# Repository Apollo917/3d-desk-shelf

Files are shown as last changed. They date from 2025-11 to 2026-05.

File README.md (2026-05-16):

<div align="center">

# TDS | Tubed Desk Shelf

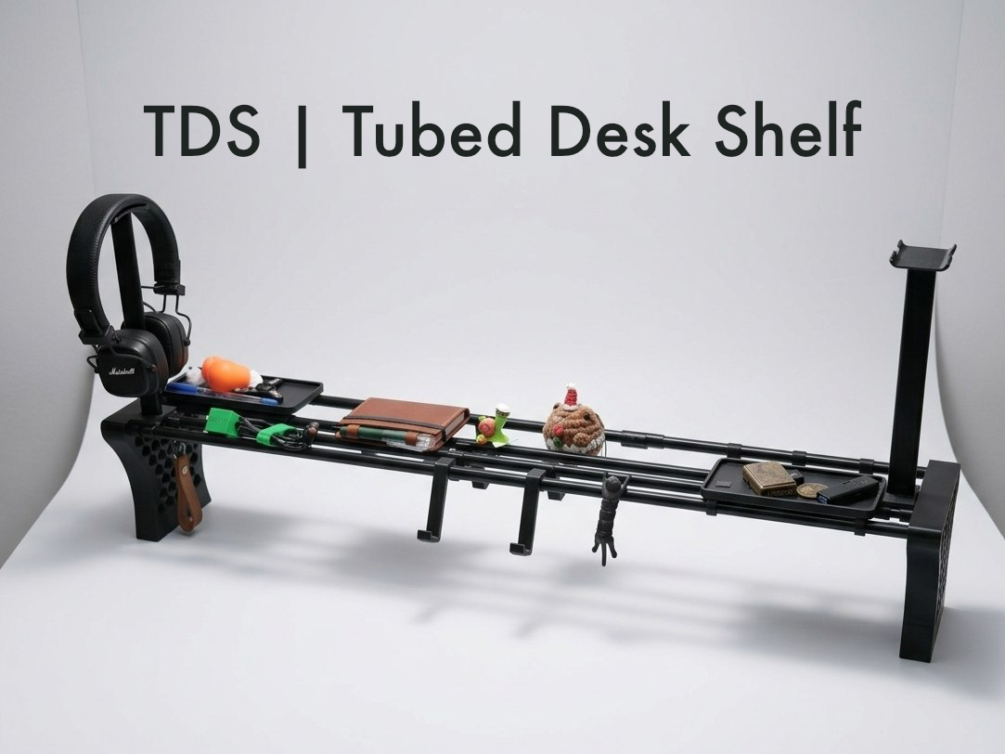
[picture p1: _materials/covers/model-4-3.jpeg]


</div>
<br>

**TDS** is an open-source, 3D-printable modular system designed to organize and elevate your workspace.
The structure is built around side supports and five 13mm-diameter tubes/rods of any material - such as aluminum, wood,
or carbon fiber. These core elements form the basic TDS, which you can secure it to your workspace using the dedicated
table mounts and expand its functionality with the initial set of compatible accessories, or design your own custom
additions. I also welcome your ideas and proposals for future expansions

**TDS** project was designed in **Autodesk Fusion** and the repository includes both the **Fusion project files** and
**.3mf files** preconfigured for the **Bambu Lab P1S** 3D printer

## Links

- [Maker World](https://makerworld.com/en/models/2803112-tds-tubed-desk-shelf#profileId-3118631)

## Ecosystem

- **Main parts**
    - [Tubed Desk Shelf](tubed-desk-shelf)
- **Accessories**
    - [Intermediate Supports](intermediate-supports)
    - [Headphones stand](headphones-stand)
    - [Tray](tray)
    - [Phone stand](phone-stand)
    - [Notebooks holder](notebook-holder)
    - [Cables holder](cables-holder)
    - [Headphones stand base](headphones-stand-base)
    - [dev kit](dev-kit)

## Specs

### Dimensions

- **Height:** 150mm
- **Width:** depends on the tube length you choose
- ⚠️ **NOTE** ⚠️
    - When marking the holes, keep in mind that each screw hole should be positioned **~39mm behind the front edge of
      the side stand** - this ensures that the shelf will sit exactly where you want it on your desk
    - Keep in mind that some accessories, or certain ways of using them, may require additional vertical space -
      consider this when positioning the shelf

### Required materials

- ~292g of PLA filament for the base shelf
- ~445g of PLA filament for the base shelf and accessories
- 5 tubes/rods with a 13mm outer diameter
- 2 x M4 x 30mm screws
    - The screws length depends on your desk thickness

## Preview

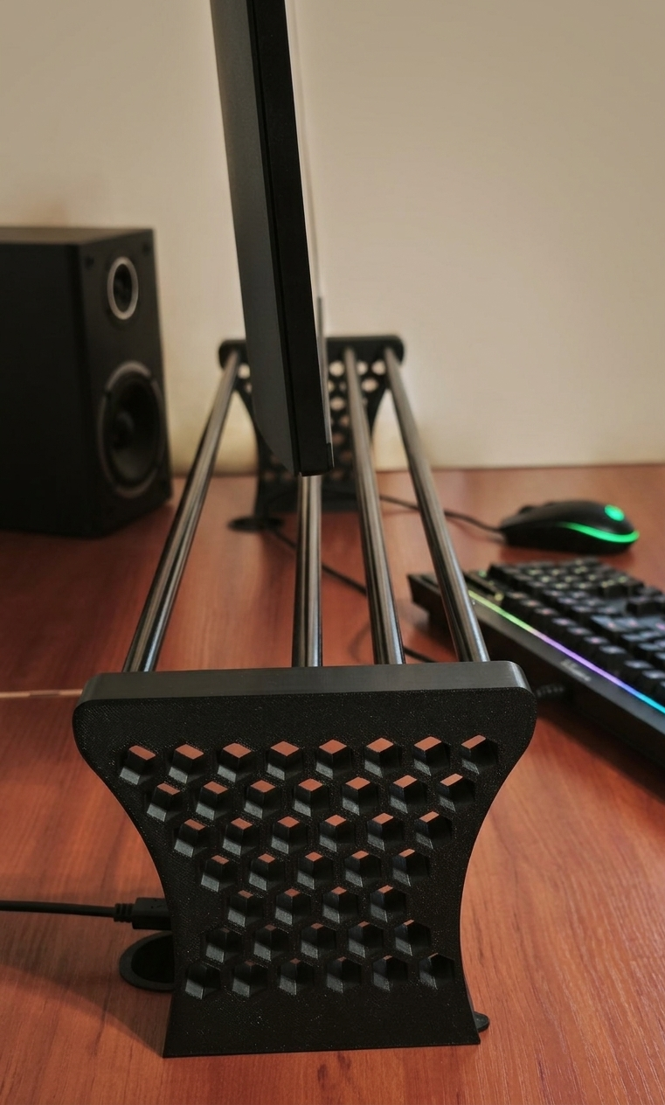
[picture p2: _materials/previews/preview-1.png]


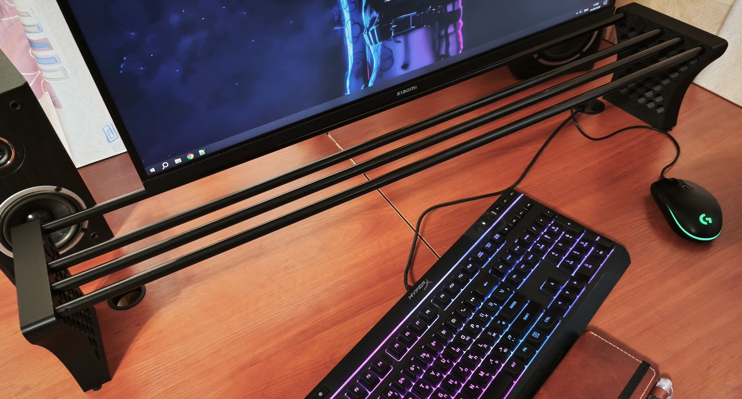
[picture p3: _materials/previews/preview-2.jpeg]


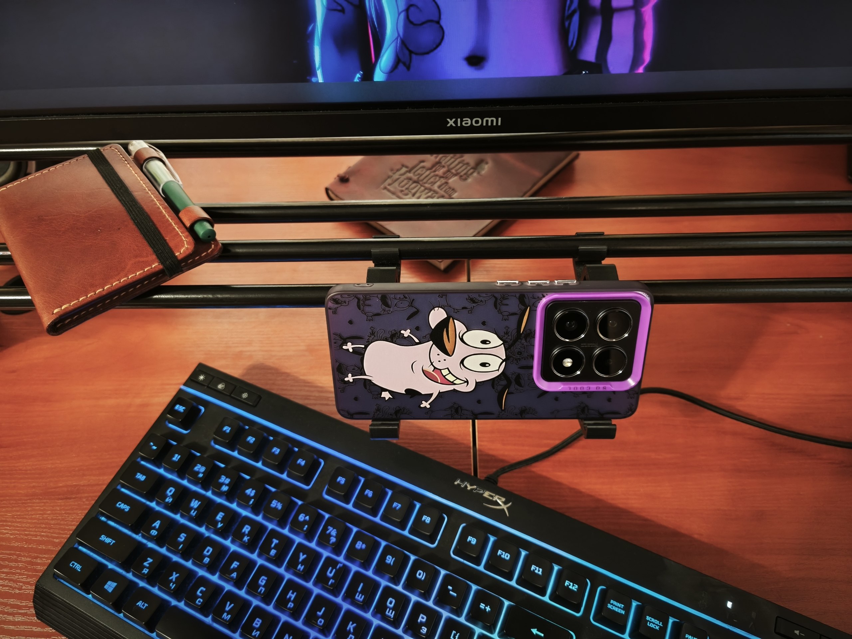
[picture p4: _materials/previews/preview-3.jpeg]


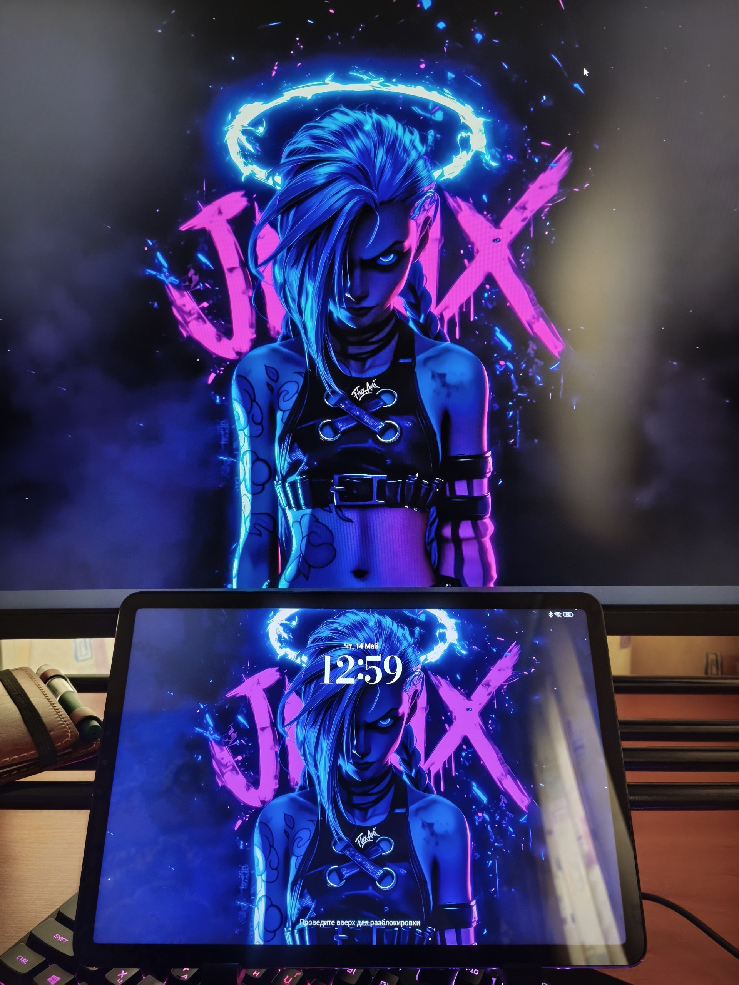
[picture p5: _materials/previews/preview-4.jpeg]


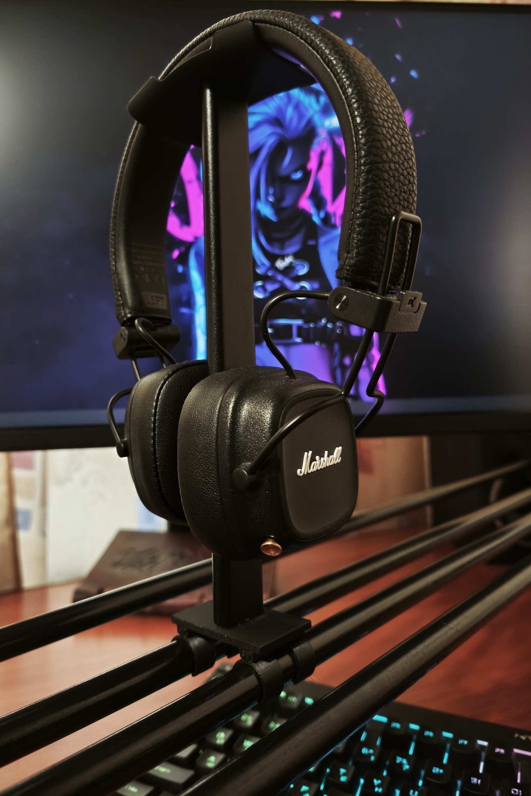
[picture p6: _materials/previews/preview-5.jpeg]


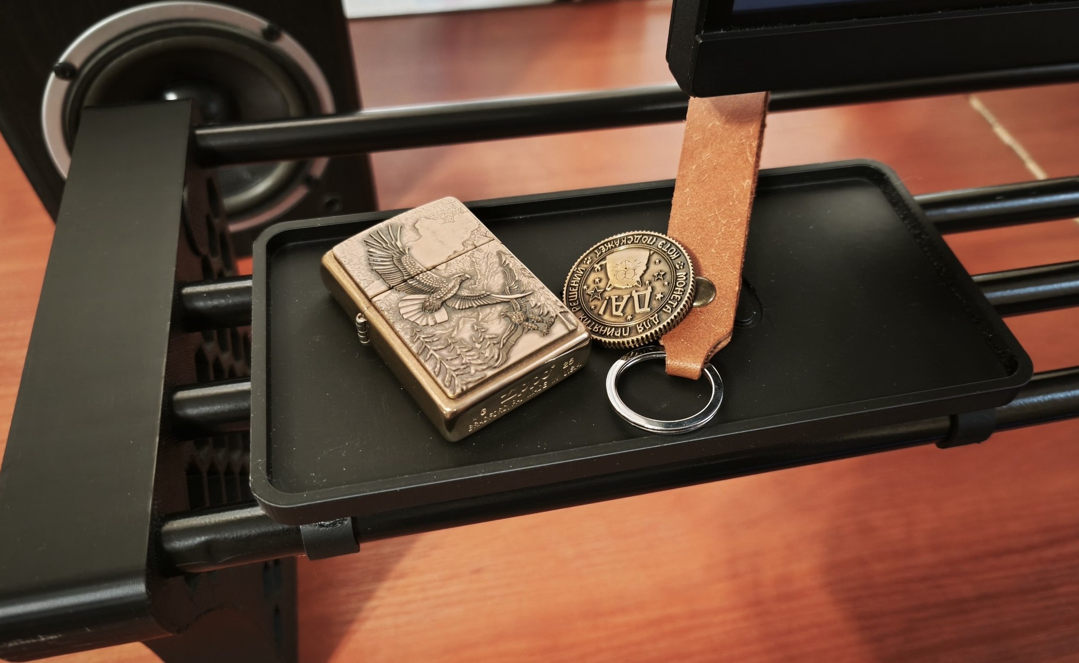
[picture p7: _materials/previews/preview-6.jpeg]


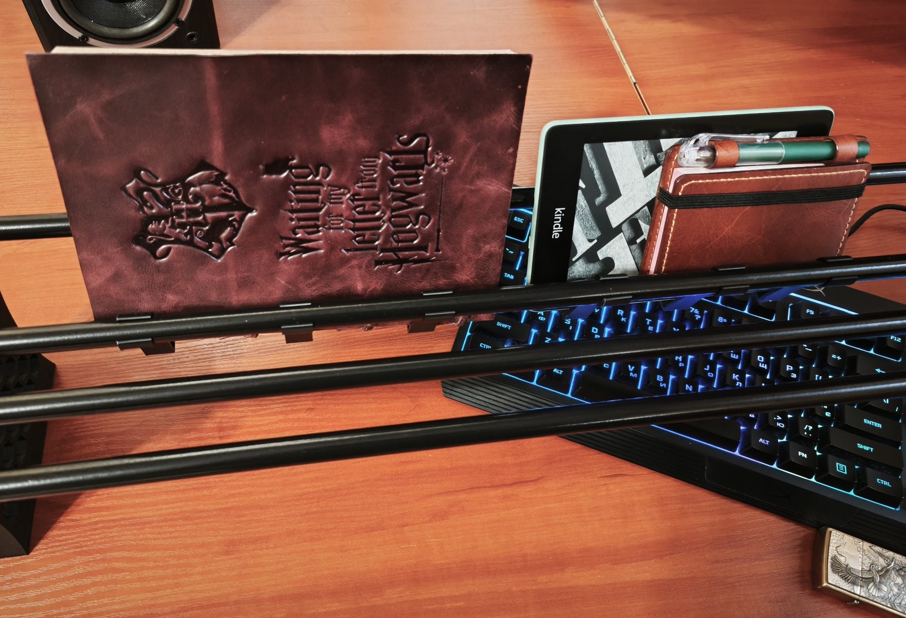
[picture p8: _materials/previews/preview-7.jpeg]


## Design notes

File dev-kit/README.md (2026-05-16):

### Dev kit

A set of essential components designed to bootstrap the development process for your own TDS accessories

## Files

- [Bambu Studio .3mf file](templates.3mf)
- [Fusion .f3d file](templates.f3d)
- [.step file](templates.step)

## Preview

### 3D

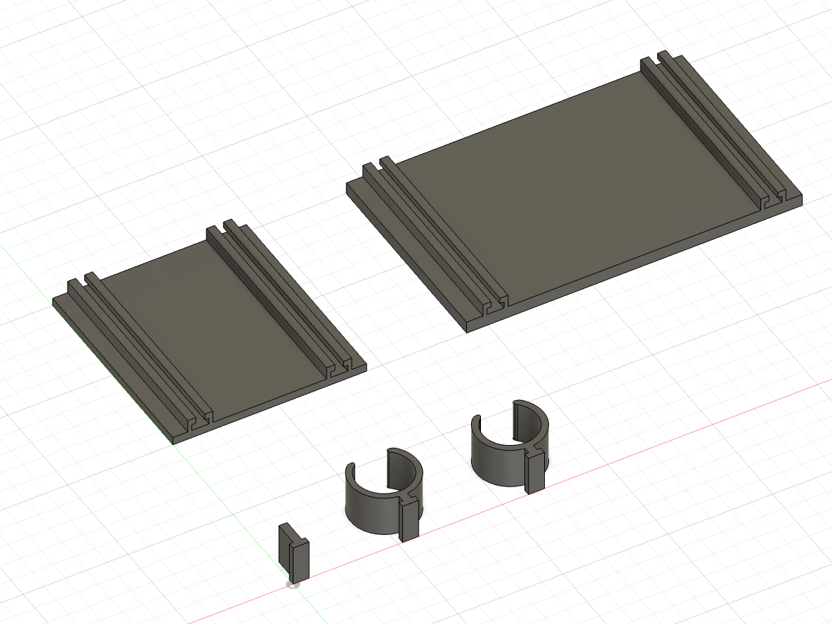
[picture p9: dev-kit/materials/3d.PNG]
Tube brackets


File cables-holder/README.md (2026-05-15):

# Cables holder

TDS-compatible accessory that keeps your keyboard, mouse, or other cables organized. You can also use it to hang small
accessories or tools

## Specs

### Required materials

**Filament required:** ~3g

## Files

- [Bambu Studio .3mf file](cables-holder.3mf)
- [Fusion .f3d file](cables-holder.f3d)
- [.step file](cables-holder.step)

## Preview

### 3D

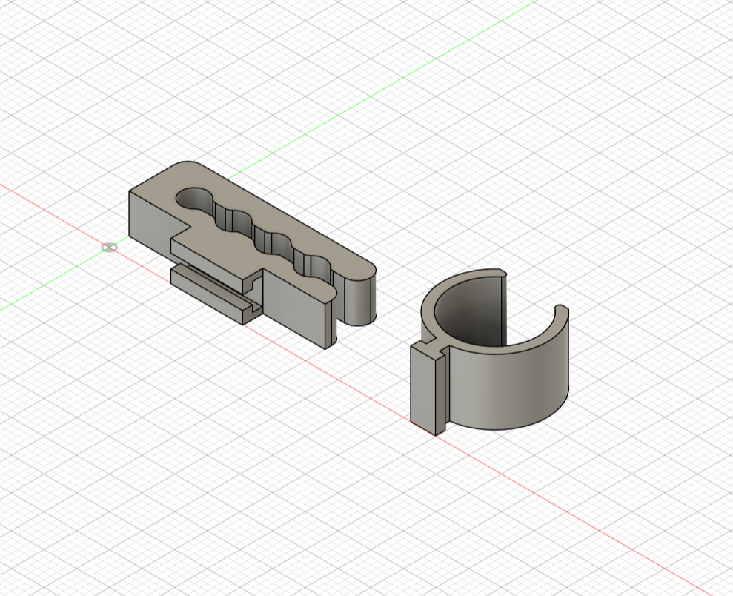
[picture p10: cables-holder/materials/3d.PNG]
Cables holder


### Printed

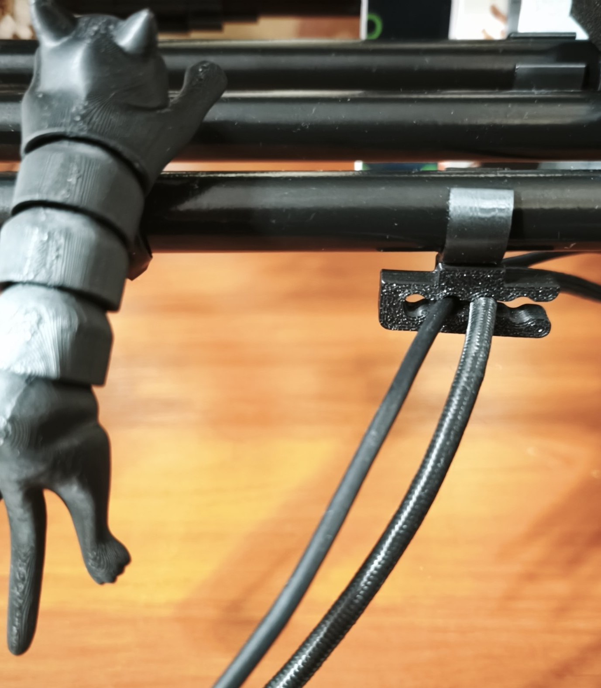
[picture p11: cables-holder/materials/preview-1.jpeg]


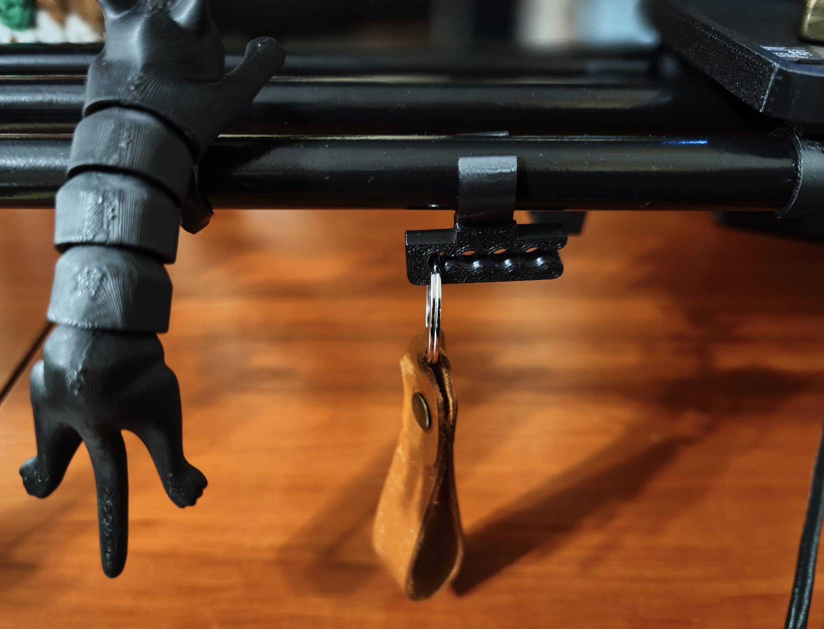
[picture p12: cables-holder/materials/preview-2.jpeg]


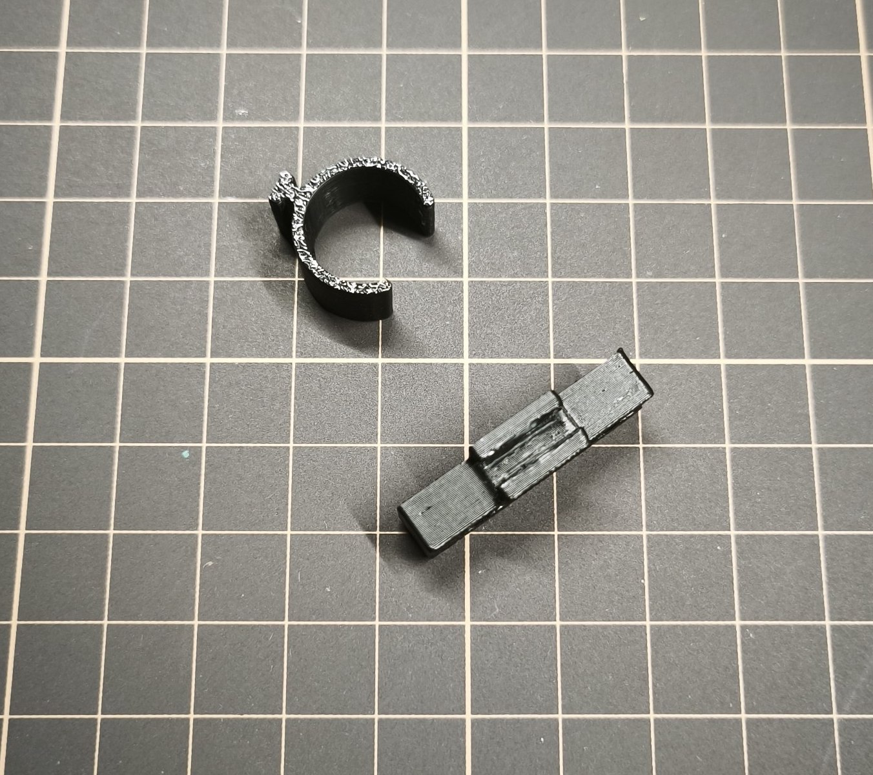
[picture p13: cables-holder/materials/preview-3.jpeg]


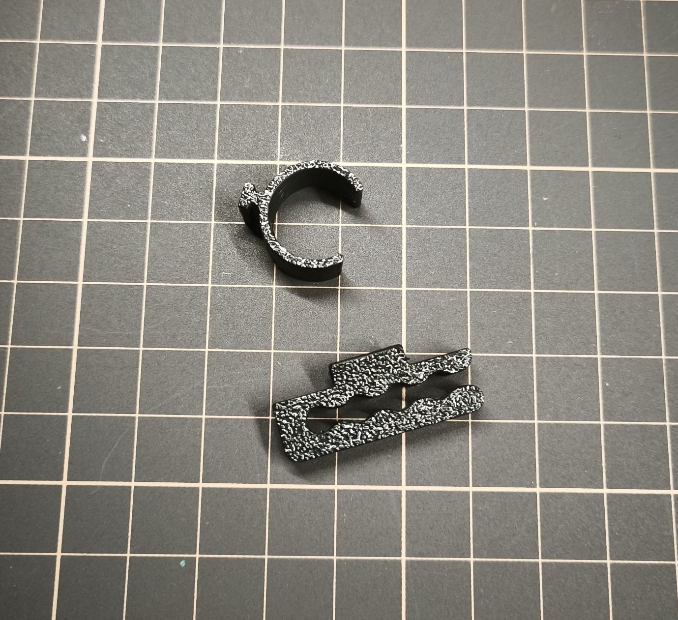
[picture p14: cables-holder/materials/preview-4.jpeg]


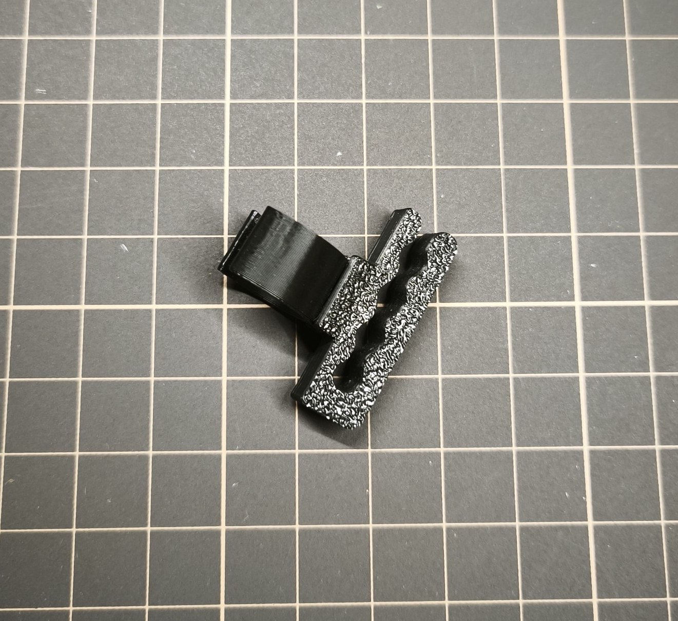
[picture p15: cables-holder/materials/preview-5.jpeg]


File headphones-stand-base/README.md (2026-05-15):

# Headphones stand base

A TDS-compatible replacement for the original baseplate, providing a stable, space-saving mounting solution for your
headphones

## Specs

### Required materials

**Filament required:** ~9g

## Files

- [Bambu Studio .3mf file](headphones-stand-base.3mf)
- [Fusion .f3d file](headphones-stand-base.f3d)
- [.step file](headphones-stand-base.step)

## Preview

### 3D

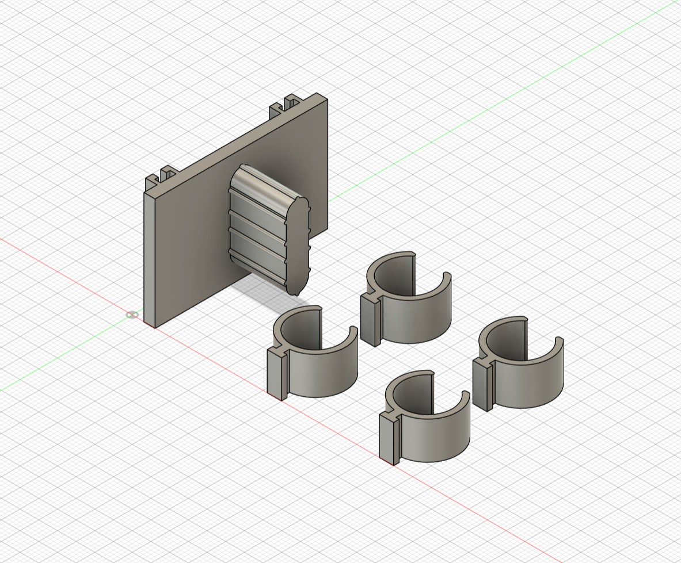
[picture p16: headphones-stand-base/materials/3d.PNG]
Headphones stand base


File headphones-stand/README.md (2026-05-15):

# Headphones stand

TDS-compatible headphones stand, designed to integrate with the shelf’s tube system, providing a stable and space-saving
mounting solution for your headphones

## Specs

### Required materials

**Filament required:** ~46g

## Files

- [Bambu Studio .3mf file](headphones-stand.3mf)
- [Fusion .f3d file](headphones-stand.f3d)
- [.step file](headphones-stand.step)

## Preview

### 3D

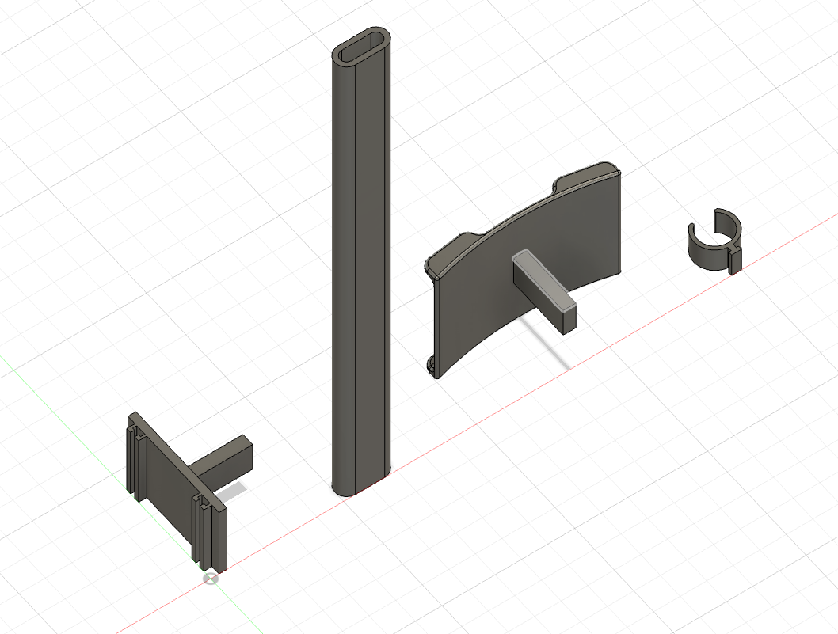
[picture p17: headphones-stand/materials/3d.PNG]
Headphones stand base


### Printed

Shelf mounts

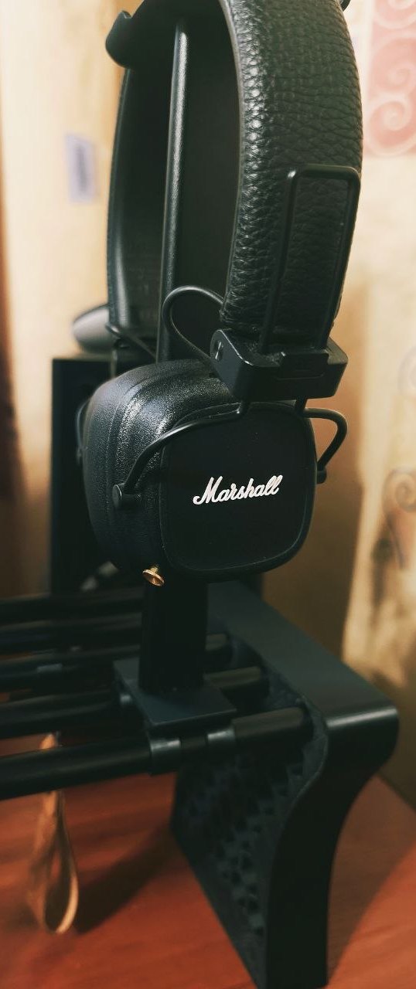
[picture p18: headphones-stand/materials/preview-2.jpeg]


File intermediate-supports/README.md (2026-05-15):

# Intermediate Supports

This extension provides optional structural reinforcement for high-payload scenarios. It is designed to interface
seamlessly with the existing architecture when center-loading (e.g. monitor, etc.) is required

Supports utilize a 13.6mm bore, engineered for a high-clearance "slide-on" fit to ensure effortless positioning
along the support tubes. For users seeking a secure but non-permanent installation, the base is compatible with
double-sided adhesive tape to prevent shifting during use, as the component's main function is to manage vertical
pressure

**Supports come in two designs**

- **Mountable:** includes an integrated base for direct desktop fixation
- **Slim:** a minimalist profile optimized for vertical bracing with a reduced footprint

## Specs

### Required materials

- **Mountable support**
    - ~144g of PLA filament
    - 2 x M4 x 30mm screws
        - The screws length depends on your desk thickness
- **Slim support**
    - ~80g of PLA filament

## Files

- [Bambu Studio .3mf file](intermediate-supports.3mf)
- [Fusion .f3d file](intermediate-supports.f3d)
- [.step file](intermediate-supports.step)

## Preview

### 3D

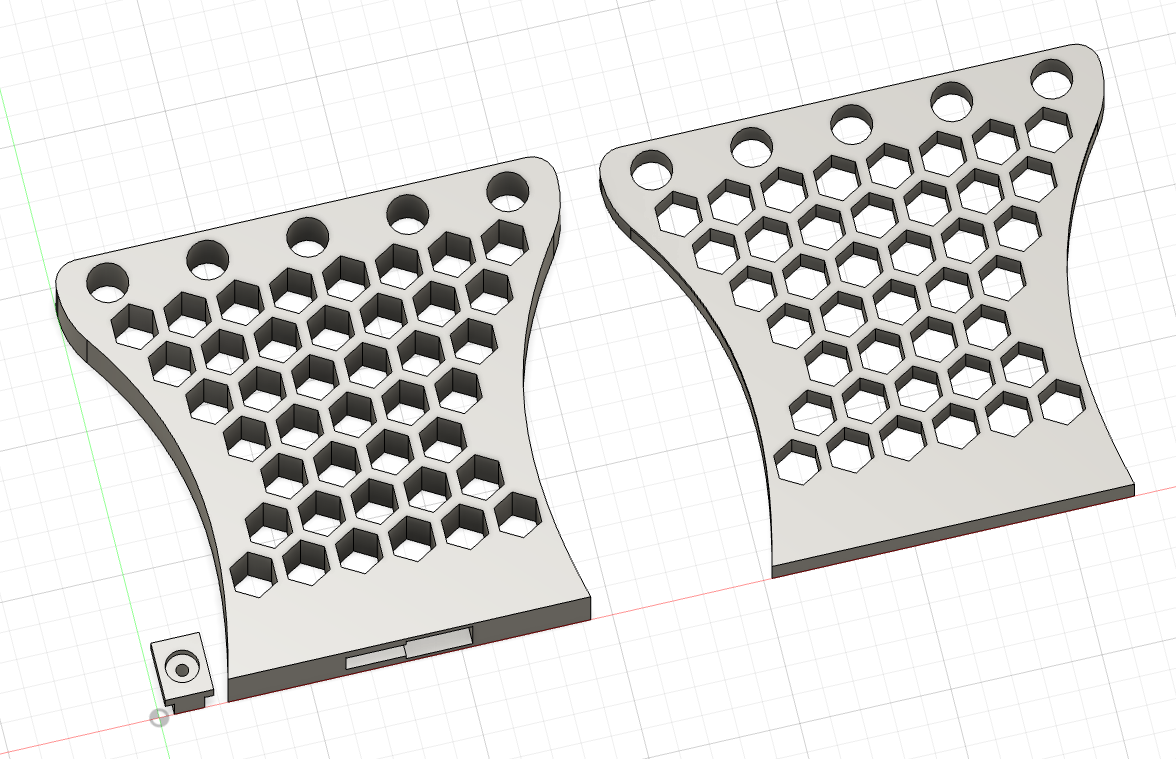
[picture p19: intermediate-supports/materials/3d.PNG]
Shelf mounts


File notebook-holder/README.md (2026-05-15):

### Notebook holder

TDS-compatible flexible holder that attaches to the shelf’s tube system and can hold notebooks, books, or other flat
items. It can be mounted between neighboring or more distant tubes

## Specs

### Required materials

**Filament required:** ~14g for the pair

## Files

- [Bambu Studio .3mf file](notebook-holder.3mf)
- [Fusion .f3d file](notebook-holder.f3d)
- [.step file](notebook-holder.step)

## Preview

### 3D

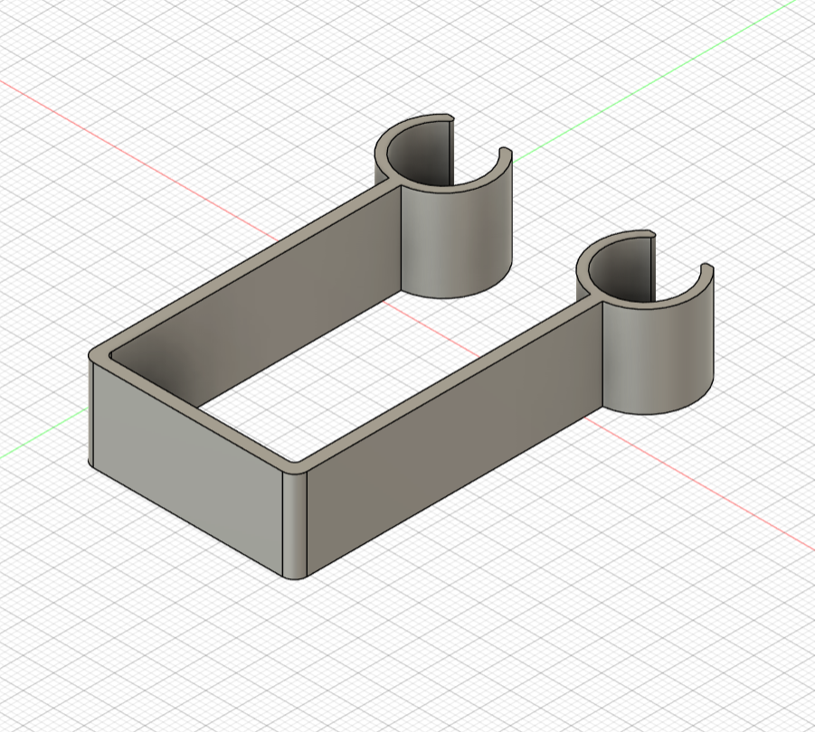
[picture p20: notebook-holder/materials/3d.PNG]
Notebooks holder


### Printed

Shelf mounts

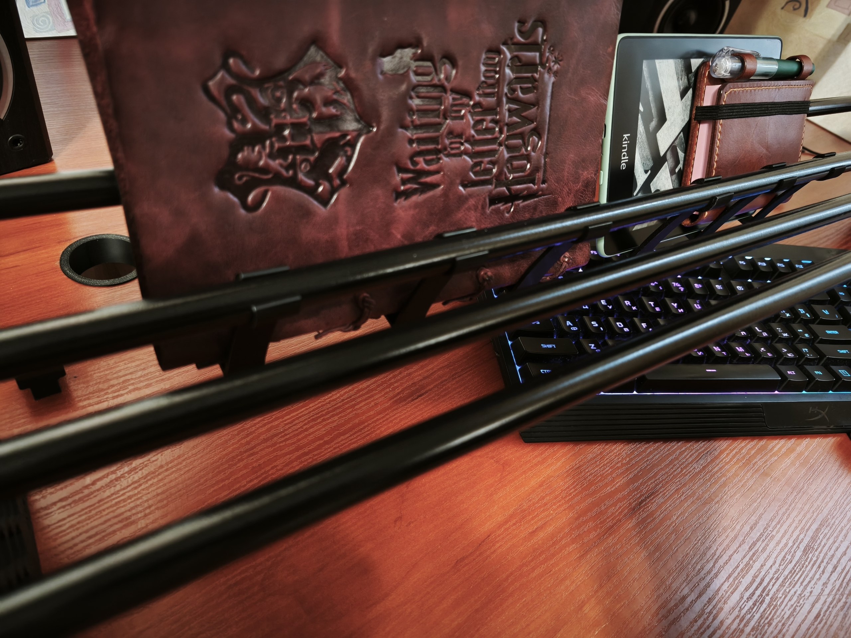
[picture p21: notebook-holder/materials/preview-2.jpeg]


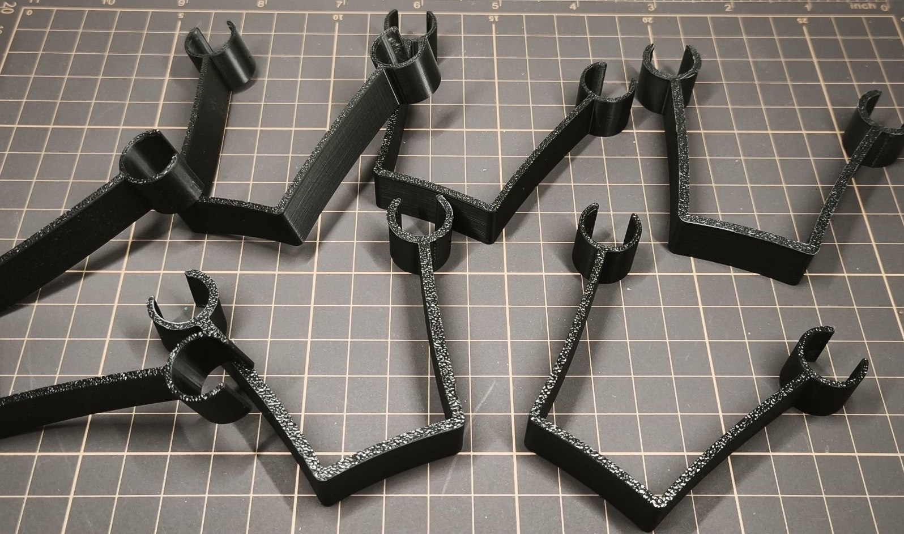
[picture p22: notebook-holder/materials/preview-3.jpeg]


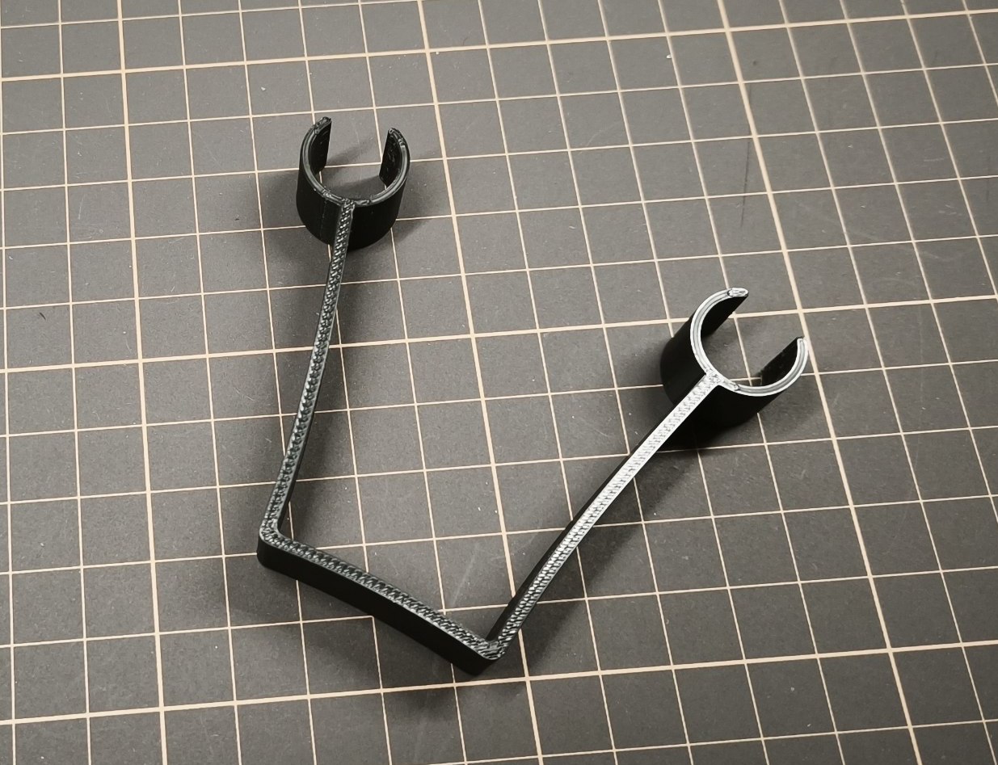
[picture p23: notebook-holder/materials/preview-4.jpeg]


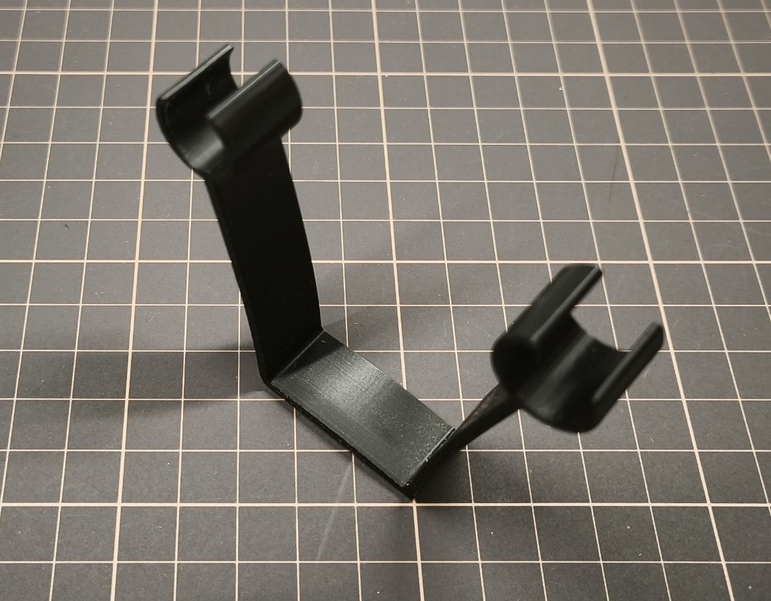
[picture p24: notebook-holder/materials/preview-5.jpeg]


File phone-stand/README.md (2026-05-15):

# Phone stand

TDS-compatible width-adjustable stand suitable for holding various devices such as phones, tablets, e-readers, etc.

## Specs

### Required materials

**Filament required:** ~22g for the pair

## Files

- [Bambu Studio .3mf file](phone-stand.3mf)
- [Fusion .f3d file](phone-stand.f3d)
- [.step file](phone-stand.step)

## Preview

### 3D

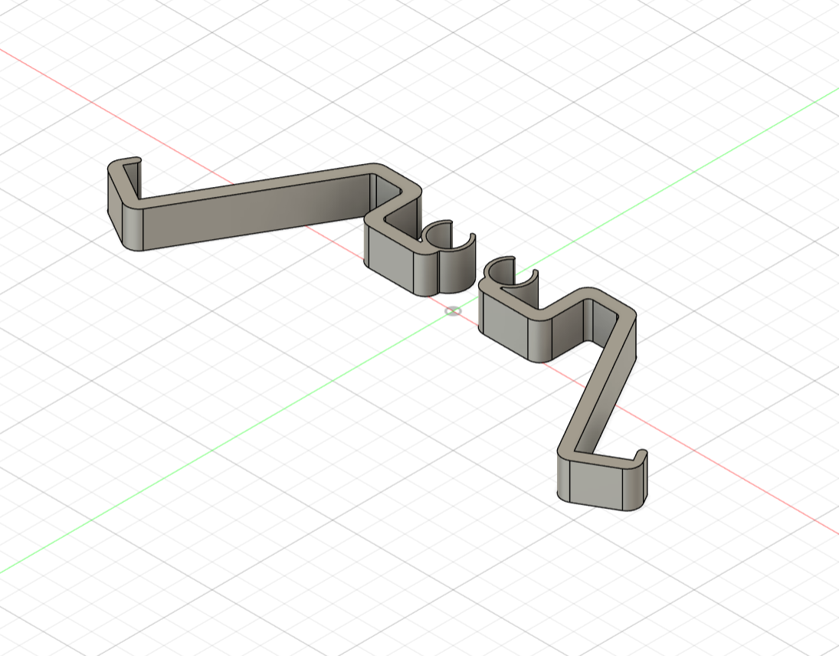
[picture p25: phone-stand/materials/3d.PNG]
Phone stand


### Printed

Shelf mounts

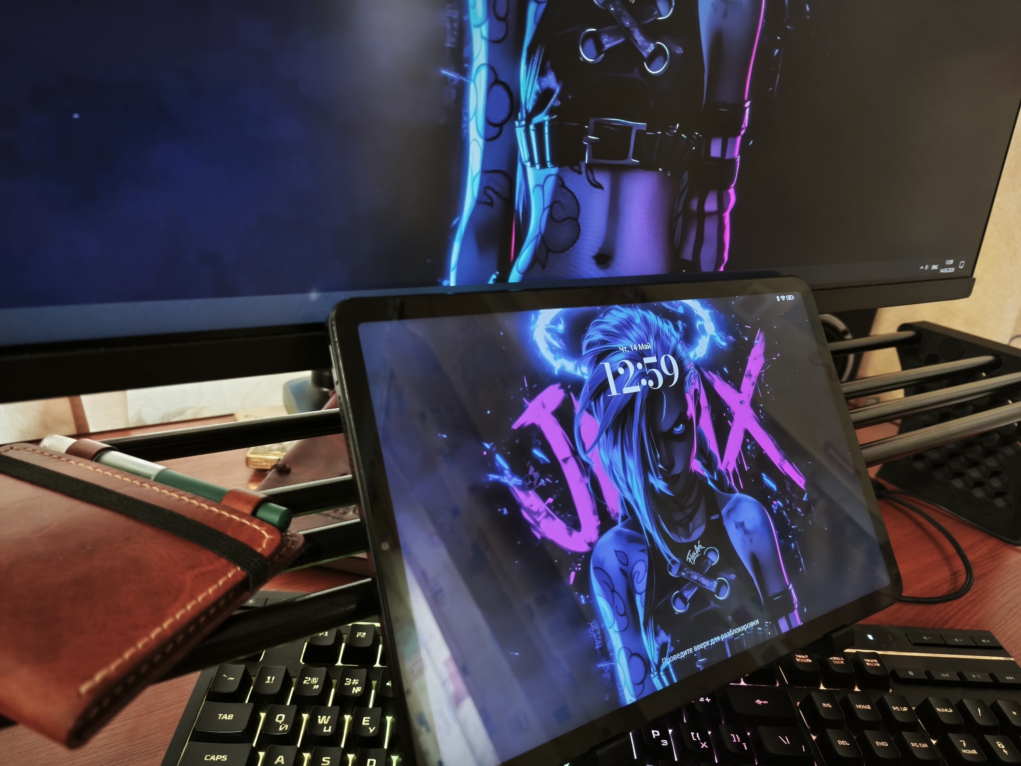
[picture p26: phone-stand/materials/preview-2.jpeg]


Shelf mounts

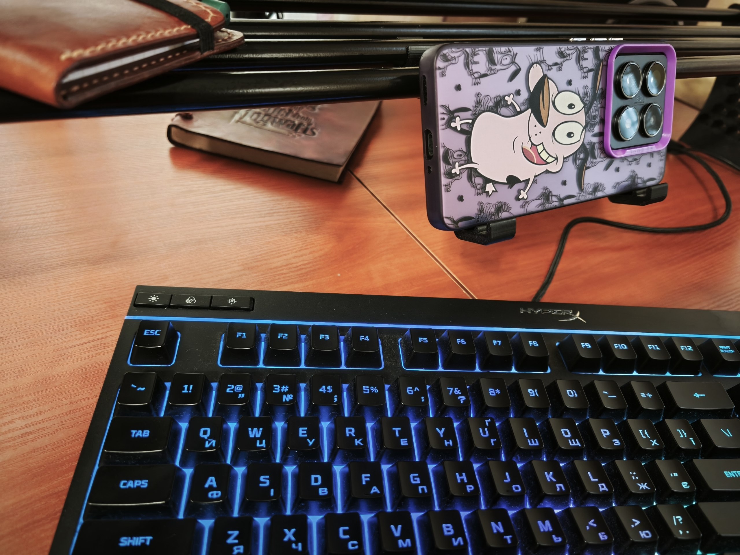
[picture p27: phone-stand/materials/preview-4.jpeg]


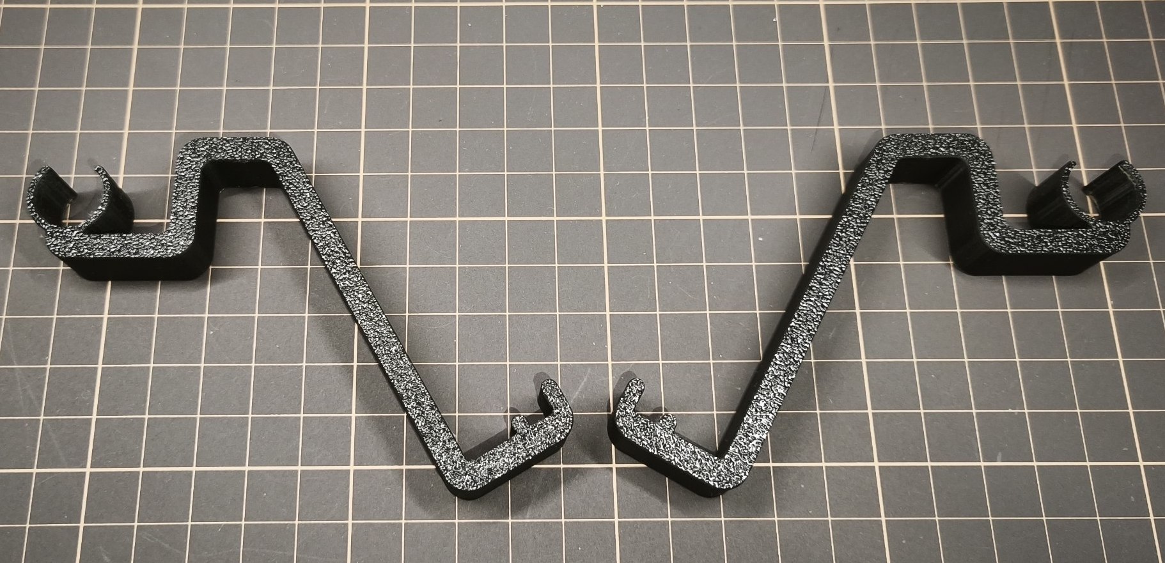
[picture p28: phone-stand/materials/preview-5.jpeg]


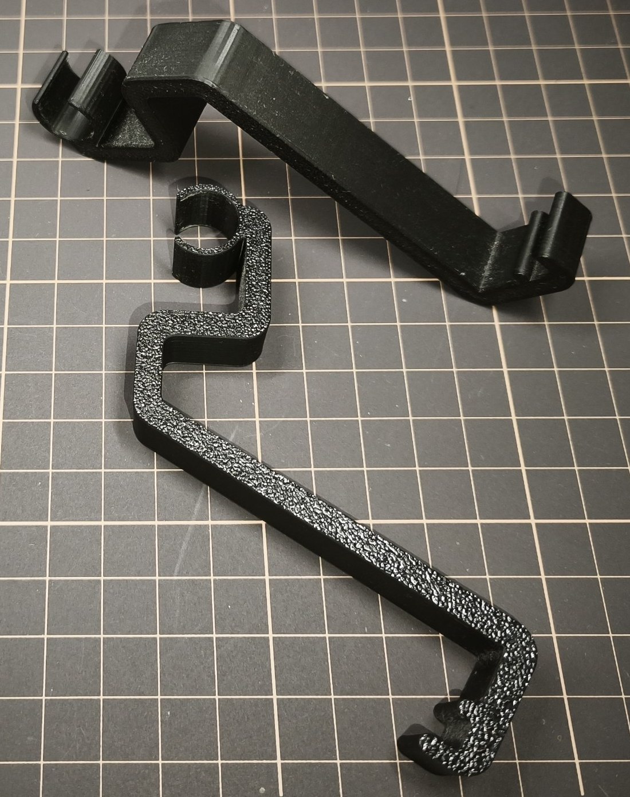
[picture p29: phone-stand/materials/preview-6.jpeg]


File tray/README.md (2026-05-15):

# Tray

TDS-compatible tray accessory, that provides convenient storage for frequently used pens, cables, and small items

## Specs

### Required materials

**Filament required:** ~59g

## Files

- [Bambu Studio .3mf file](tray.3mf)
- [Fusion .f3d file](tray.f3d)
- [.step file](tray.step)

## Preview

### 3D

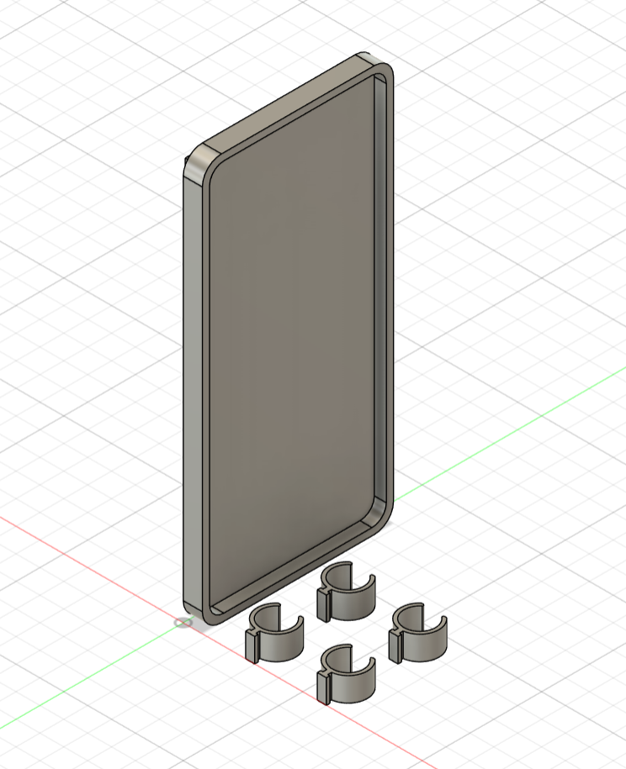
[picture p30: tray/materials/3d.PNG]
Tray


### Printed

Shelf mounts

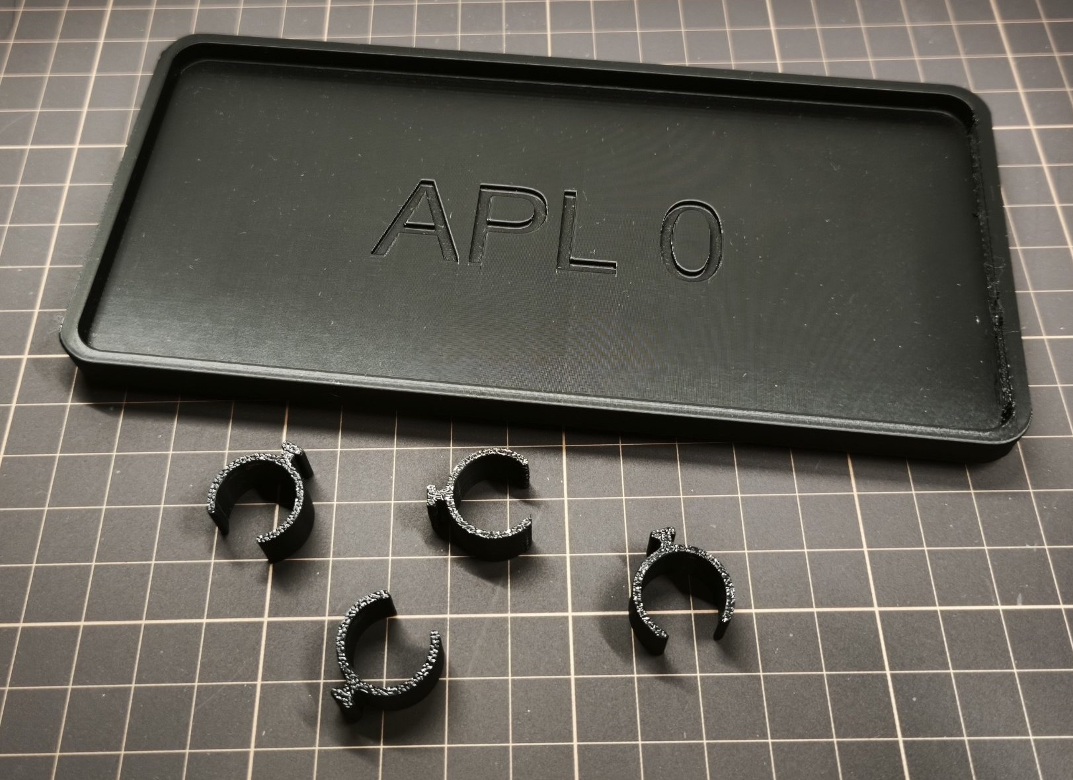
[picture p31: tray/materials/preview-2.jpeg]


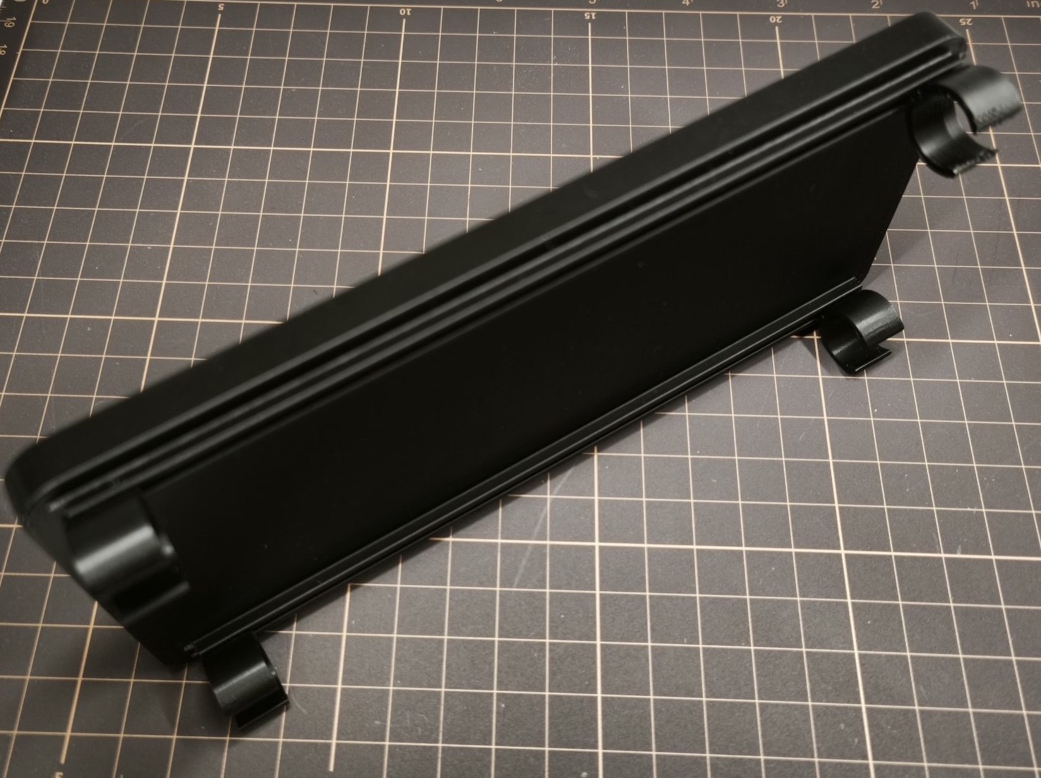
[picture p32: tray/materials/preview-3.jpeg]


Shelf mounts

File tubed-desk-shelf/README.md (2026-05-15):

# TDS | Tubed Desk Shelf

These are the essential TDS parts, forming the basic shelf (TDS) structure from which the entire system is built:

- **Side Supports**: the primary structural frames that hold the rods in place and define the shelf's profile
- **Table Mounts:** dedicated hardware that allows the side supports to be mounted securely onto the tabletop

Together, these components establish the TDS, ready for further customization and accessories

## Specs

### Dimensions

- **Height:** 150mm
    - ⚠️ Keep in mind that some accessories, or certain ways of using them, may require additional vertical space -
      consider this when positioning the shelf
- **Distance between tube centers:** 33.1 mm
- **Distance between tubes:** 20 mm

### Required materials

- ~292g of PLA filament
- 5 tubes/rods with a 13mm outer diameter
- 2 x M4 x 30mm screws
    - The screws length depends on your desk thickness

### Installation

- Slide your tubes or rods into the designated openings on each side of the shelf stand
- The number of tubes/rods and their configuration can be adjusted based on your specific needs and workspace
  requirements
- Choose the desired position for your shelf
- ⚠️ When marking the holes, keep in mind that each screw hole should be
  positioned **~39mm behind the front edge of the side stand** - this ensures that the shelf will sit exactly
  where you want it on your desk
- To secure the mounts, drill one hole into the tabletop for an M4 screw on each side of the shelf
- Secure the mounts with M4 screws, which can be threaded straight into the mount itself
- Place the side stands onto the installed shelf mounts and slide them away from you (toward the back
  of the desk) until they lock in place

## Files

- [Bambu Studio .3mf file](tubed-desk-shelf.3mf)
- [Fusion .f3d file](tubed-desk-shelf.f3d)
- [.step file](tubed-desk-shelf.step)

## Preview

### 3D

Shelf mounts

### Printed

Shelf mounts

Shelf mounts

Shelf mounts

Shelf mounts

Shelf mounts

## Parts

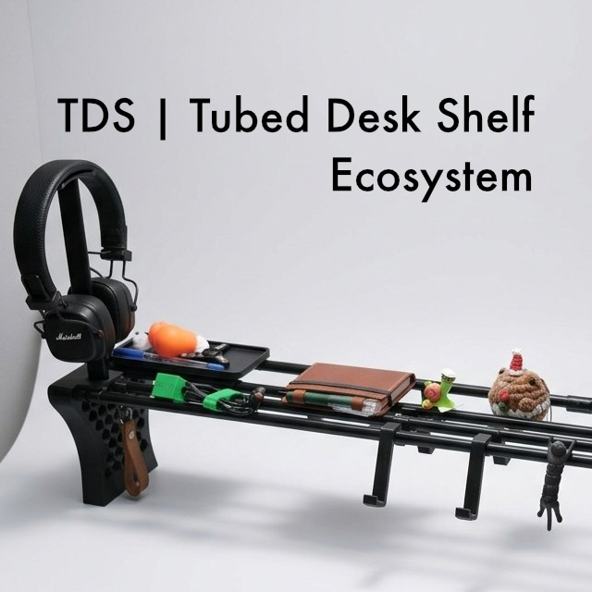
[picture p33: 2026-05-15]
_materials/covers/model-ecosystem-1-1.jpeg

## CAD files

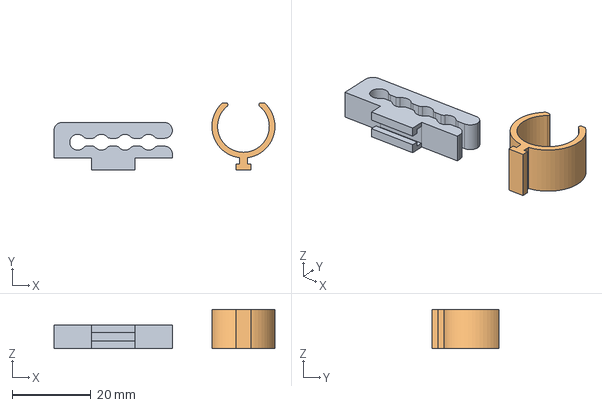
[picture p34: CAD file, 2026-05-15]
cables-holder/cables-holder.step
56.0 x 17.1 x 10.0 mm

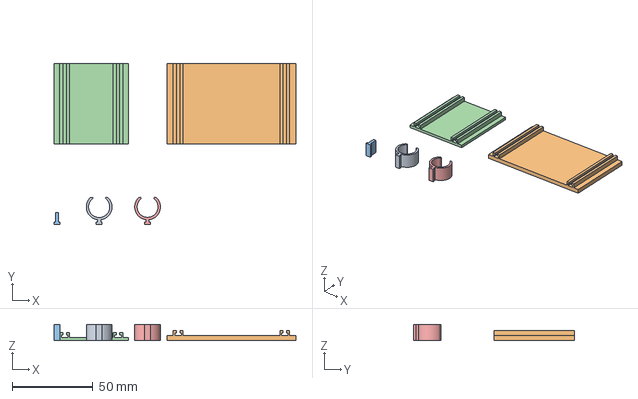
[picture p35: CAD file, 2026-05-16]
dev-kit/dev-kit.step
150.0 x 100.0 x 10.0 mm

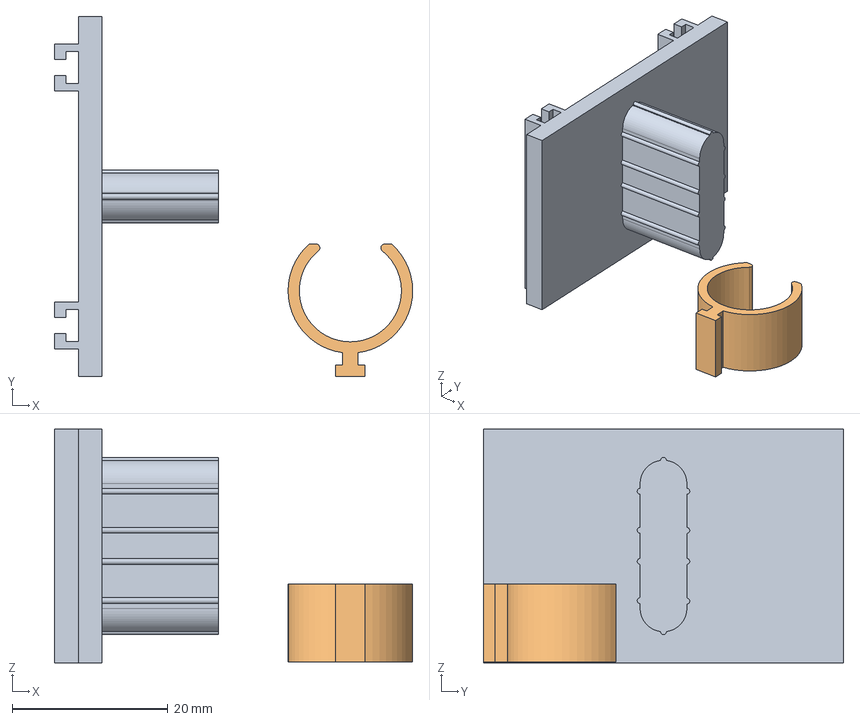
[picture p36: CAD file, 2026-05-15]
headphones-stand-base/headphones-stand-base.step
46.0 x 46.2 x 30.0 mm

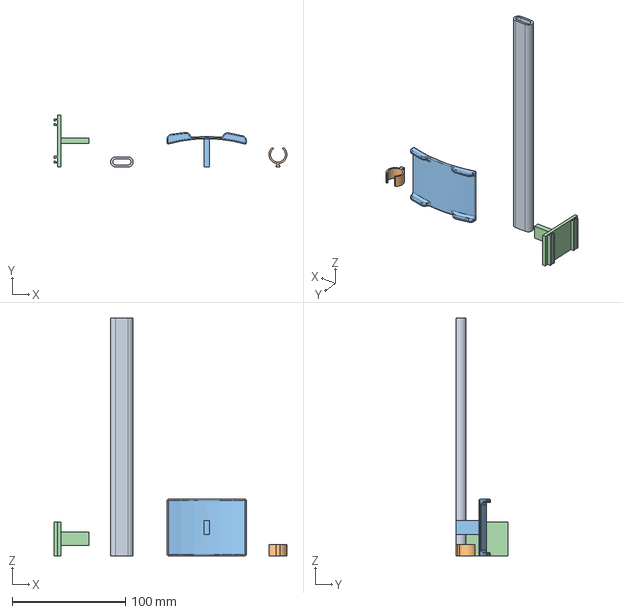
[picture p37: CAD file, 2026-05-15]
headphones-stand/headphones-stand.step
206.0 x 46.3 x 210.0 mm

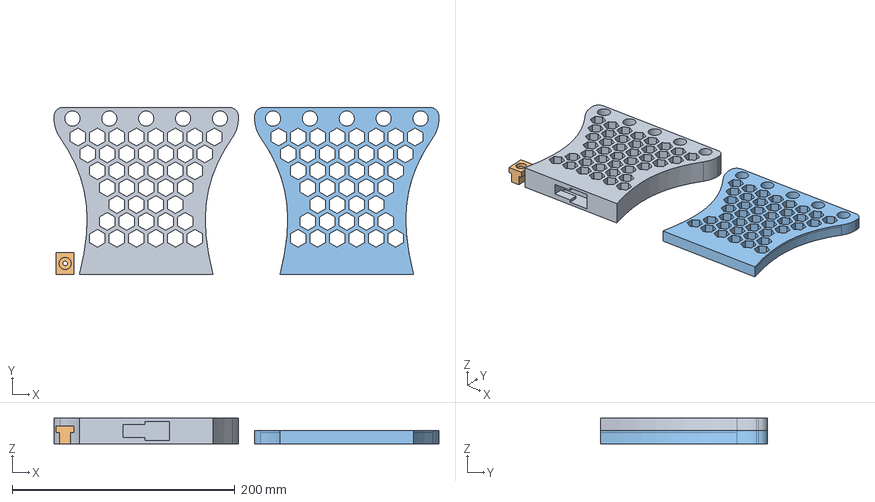
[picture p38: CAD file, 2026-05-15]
intermediate-supports/intermediate-supports.step
345.5 x 150.0 x 23.0 mm

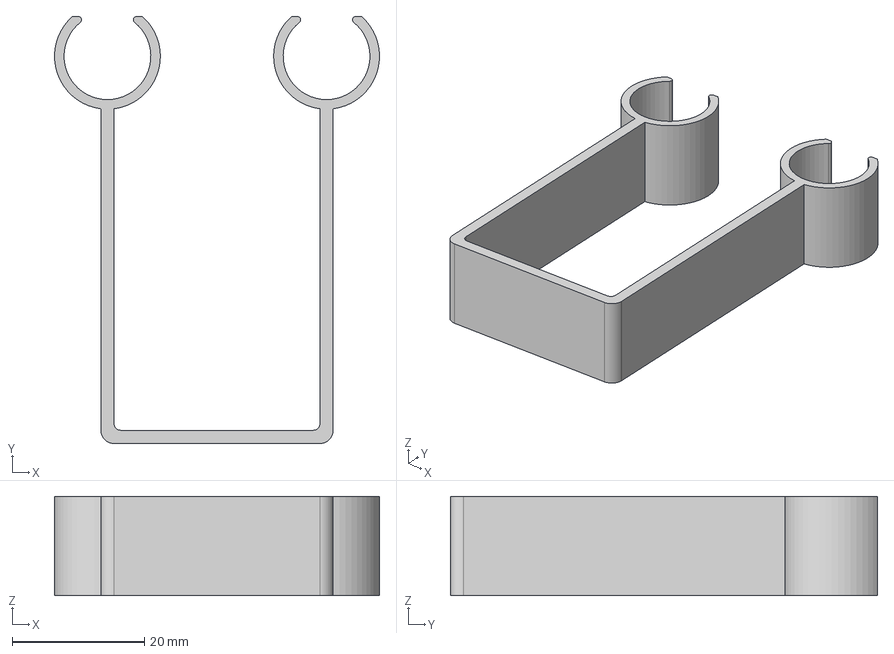
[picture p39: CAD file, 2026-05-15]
notebook-holder/notebook-holder.step
49.1 x 64.5 x 15.0 mm

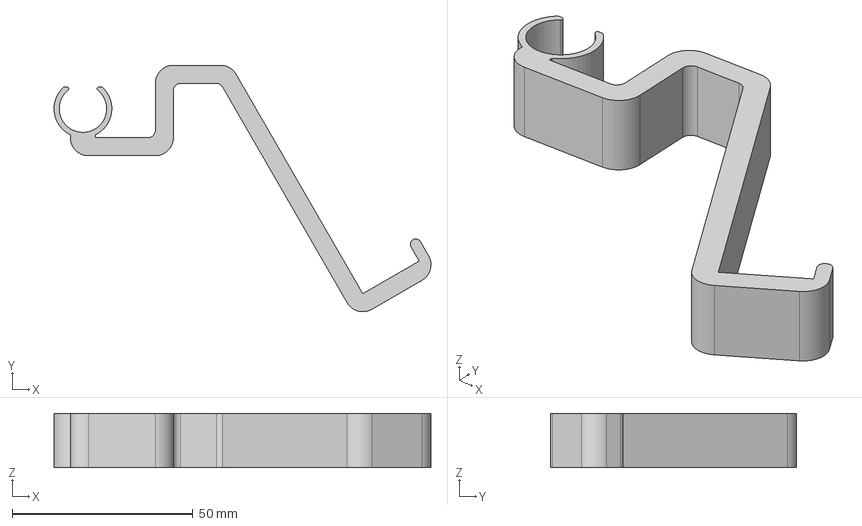
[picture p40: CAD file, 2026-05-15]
phone-stand/phone-stand.step
104.2 x 68.1 x 15.0 mm

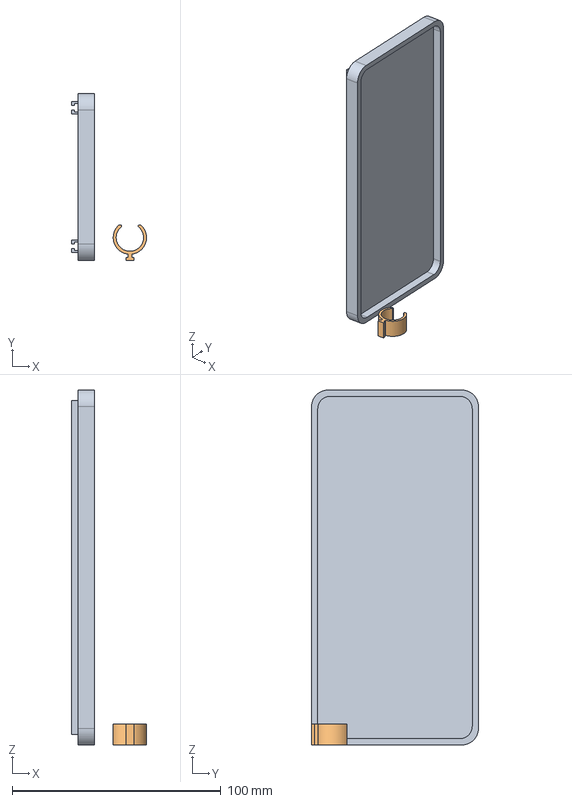
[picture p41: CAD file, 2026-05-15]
tray/tray.step
36.0 x 80.0 x 170.0 mm

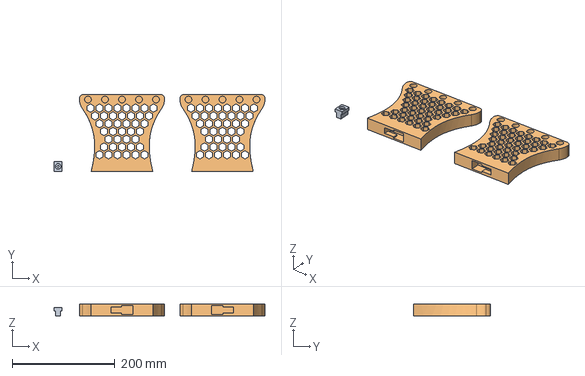
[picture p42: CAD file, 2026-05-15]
tubed-desk-shelf/tubed-desk-shelf.step
410.5 x 150.0 x 23.0 mm

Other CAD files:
cables-holder/cables-holder.3mf
cables-holder/cables-holder.f3d
dev-kit/dev-kit.3mf
dev-kit/dev-kit.f3d
headphones-stand-base/headphones-stand-base.3mf
headphones-stand-base/headphones-stand-base.f3d
headphones-stand/headphones-stand.3mf
headphones-stand/headphones-stand.f3d
intermediate-supports/intermediate-supports.3mf
intermediate-supports/intermediate-supports.f3d
notebook-holder/notebook-holder.3mf
notebook-holder/notebook-holder.f3d
phone-stand/phone-stand.3mf
phone-stand/phone-stand.f3d
tray/Tray.3mf
tray/Tray.f3d
tubed-desk-shelf/tubed-desk-shelf.3mf
tubed-desk-shelf/tubed-desk-shelf.f3d

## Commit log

2025-11-05 shelf mounts
    [Shelf mounts.3mf, Shelf mounts.f3d]
2025-11-05 side stands
    [Side stands.3mf, Side stands.f3d]
2025-11-05 cables holder
    [Cables holder.3mf, Cables holder.f3d]
2025-11-05 headphones stand base
    [Headphones stand base.3mf, Headphones stand base.f3d]
2025-11-05 notebook holder
    [Notebook holder.3mf, Notebook holder.f3d]
2025-11-05 phone stand
    [Phone stand.3mf, Phone stand.f3d]
2025-11-05 tube brackets
    [Tube brackets.3mf, Tube brackets.f3d]
2026-05-13 minor fixes and adjustments (#3)
    [Cables holder.3mf, Cables holder.f3d, Headphones stand base.3mf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]
2026-05-13 rebranding (#4)
    [Cables holder.3mf, Headphones stand base.3mf, Headphones stand.3mf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]
2026-05-13 Headphones stand (#5)
    * Headphones stand refactored and fixed
    * Print preset plate names are unified
    [Cables holder.3mf, Headphones stand base.3mf, Headphones stand.3mf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]
2026-05-14 fixes and description updates (#6)
    [shelf.3mf, shelf.f3d, tubed-desk-shelf.3mf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]
2026-05-15 Tubed Desk Shelf minor fixes and improvements (#7)
    [tubed-desk-shelf.3mf, tubed-desk-shelf.f3d, tubed-desk-shelf.step]
2026-05-15 Intermediate Supports added (#10)
    [intermediate-supports.3mf, intermediate-supports.f3d, intermediate-supports.step]
2026-05-15 Upload prep (#11)
    [cables-holder.3mf, cables-holder.f3d, cables-holder.step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]
2026-05-15 Fix link text for Tube brackets to Templates
2026-05-16 dev kit added (#12)
    [dev-kit.3mf, dev-kit.f3d, dev-kit.step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]
